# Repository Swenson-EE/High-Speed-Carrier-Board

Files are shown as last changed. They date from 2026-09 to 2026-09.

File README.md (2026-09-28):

# LattePanda-Mu High-Speed Carrier Board

A custom carrier board designed for the **LattePanda Mu** compute module, with a focus on high-speed digital design, signal integrity, power distribution, and practical PCB design.

This project was developed to apply high-speed PCB design concepts to a real embedded computing platform. The design process incorporated concepts studied through online courses, technical forums, datasheets, and reference designs.

> **Project Status:** Fabrication
> **PCB Design Tool:** KiCad
> **Primary Focus:** High-speed digital design, power distribution, signal integrity, and embedded hardware

---

## Overview

The goal of this project is to design a custom carrier board around the LattePanda Mu rather than relying on an off-the-shelf carrier board to explore high-speed digital design concepts.

The carrier board is intended to provide practical interfaces for development and experimentation while giving me experience designing a PCB containing multiple high-speed interfaces.

### Design Goals

- Develop a custom carrier board for the LattePanda Mu
- Apply high-speed PCB layout techniques
- Develop controlled-impedance routing practices
- Maintain appropriate differential-pair geometry
- Minimize high-speed signal discontinuities
- Develop a robust power distribution network
- Practice schematic-to-PCB design workflows
- Use datasheets and reference documentation to make design decisions
- Validate the design using available electrical and PCB design tools
- Produce a board suitable for fabrication and bring-up

---

## Hardware

### Compute Module

**LattePanda Mu**

The LattePanda Mu provides the primary compute platform for the carrier board.

The carrier board interfaces with the module through its high-density connectors and routes the available interfaces to the desired peripherals and connectors.

---

## PCB Designs

<table style="background: white;">
  <tr>
    <td align="center"><b>Top Silk Screen</b><br></td>
  </tr>
  <tr>
    <td align="center"><b>Front Cu (L1)</b><br></td>
  </tr>
  <tr>
    <td align="center"><b>GND (L2)</b><br></td>
  </tr>
  <tr>
    <td align="center"><b>PWR (L3)</b><br></td>
  </tr>
  <tr>
    <td align="center"><b>Bottom Cu (L4)</b><br></td>
  </tr>
</table>

## Interfaces

The carrier board is designed around several interfaces provided by the LattePanda Mu.

| Interface | Purpose | Design Considerations |
| --- | --- | --- |
| USB | Peripheral connectivity | High-speed differential routing |
| HDMI / Display | Display output | Differential high-speed routing |
| Ethernet | Network connectivity | Differential pairs and magnetics |
| PCIe | Expansion | Controlled impedance / differential routing |
| M.2 | Expansion/storage | High-speed differential routing |
| GPIO | General-purpose I/O | Digital signal integrity |
| Power | Module and peripheral power | Power integrity / decoupling |

---

# High-Speed PCB Design

A major purpose of this project is to practice PCB design techniques applicable to high-speed digital hardware.

Rather than treating PCB traces simply as electrical connections, the design considers them as transmission lines at sufficiently high signal frequencies.

Areas being considered include:

### Controlled Impedance

High-speed interfaces are routed using appropriate controlled-impedance structures based on the PCB stackup and manufacturer's capabilities.

Examples include:

- Differential impedance
- Single-ended impedance
- Trace width
- Trace spacing
- Reference planes
- Dielectric thickness
- Copper thickness

The final trace geometries are based on the selected PCB stackup rather than relying solely on generic routing rules.

### Differential Pairs

High-speed differential interfaces are routed as matched differential pairs where required.

Design considerations include:

- Differential impedance
- Pair spacing
- Intra-pair length matching
- Continuous reference planes
- Avoiding unnecessary vias
- Minimizing discontinuities
- Maintaining consistent routing geometry

### Return Paths

High-speed signal routing considers the return current path rather than treating the signal trace independently.

Particular attention is given to:

- Continuous reference planes
- Plane transitions
- Ground vias
- Layer transitions
- Signal crossings
- Connector transitions

### Via Design

Vias can introduce discontinuities into high-speed signals.

Where applicable, the design considers:

- Via stubs
- Via placement
- Differential via geometry
- Ground-via placement
- Layer transitions
- Back-drilling requirements

---

# Power Distribution

The carrier board includes power regulation and distribution for the compute module and attached peripherals.

Power design considerations include:

- Input power requirements
- Voltage regulation
- Current requirements
- Decoupling
- Ground-plane design

Decoupling capacitors are placed with consideration for the physical connection between the capacitor, power pin, and return path rather than simply placing them near the associated component.

---

# PCB Stackup

The PCB stackup is an important part of the high-speed design.

The stackup is selected based on the requirements of the interfaces being routed and the capabilities of the intended PCB manufacturer.

Example stackup:

| Layer | Function |
| ----- | --- |
| L1 | Signal |
| L2 | Ground |
| L3 | Power |
| L4 | Signal |

The stackup is used to determine the appropriate controlled-impedance trace geometries.

---

# Research & Learning

This project is also a practical study of high-speed PCB design.

The design process has been informed by:

- LattePanda Mu documentation
- Component datasheets
- Manufacturer application notes
- PCB fabrication guidelines
- High-speed PCB design coursework
- Engineering forums
- Technical discussions
- Reference designs
- Signal-integrity design practices

The purpose of using these resources is to understand **why** particular PCB design decisions are made rather than simply reproducing an existing board.

Where external designs or reference material influence the project, the relevant source will be documented in the project documentation.

---

# Verification

Before fabrication, the design will be reviewed using:

- Electrical rule checking
- PCB design rule checking
- Connectivity verification
- Differential-pair constraints
- Length matching constraints
- Controlled-impedance calculations
- Power-tree review
- Datasheet requirement verification
- Manufacturer design-rule review

Where practical, calculations and design assumptions will be documented in the `/docs` directory.

---

# Disclaimer

This is an independent educational hardware project.

The project is intended to demonstrate my understanding and application of PCB design principles. It is not an official LattePanda design.

The design should be independently reviewed and validated before being used in a production or safety-critical application.

---

# References

- LattePanda Mu documentation
- LattePanda Mu hardware/reference documentation
- Relevant component datasheets
- PCB manufacturer fabrication specifications
- High-speed PCB design course material
- Relevant application notes and technical references

---

## Author

**Tyler Swenson**

This project was created as a hands-on embedded hardware and high-speed PCB design project, with an emphasis on understanding the engineering decisions behind the design rather than simply producing a functioning PCB.

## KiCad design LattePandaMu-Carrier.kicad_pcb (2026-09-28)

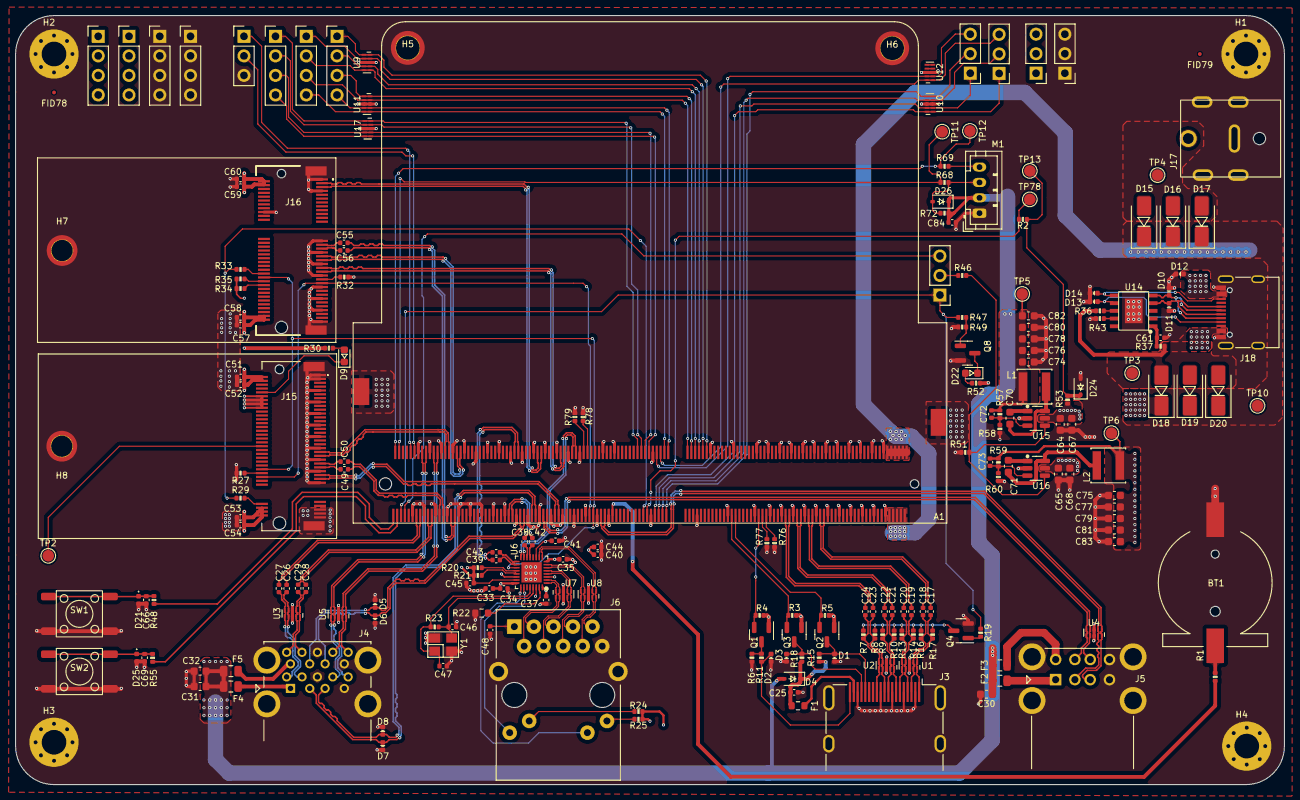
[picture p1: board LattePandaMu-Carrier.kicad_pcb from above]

Board: 4 copper layers, 165.0 x 100.0 mm, 218 parts (0 on the bottom side), 174 nets.

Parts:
A1: LattePanda_Mu; LattePanda_Module_H8.0mm_Horizontal
BT1: Battery_Cell; Battery_Holder_CR1220_S8411-45R
C17, C18, C19, C20, C21, C22, C23, C24, C25, C26, C27, C28, C29, C33, C34, C35, C37, C38, C39, C40, C41, C42, C43, C45, C48, C52, C54, C58, C60, C84: 100nF/50V; C_0402_1005Metric
C30, C31, C32, C64, C65, C67, C68, C74, C75, C76, C77, C80, C81, C82, C83: 22uF/10V; C_0603_1608Metric
C44: 10uF/50V; C_0402_1005Metric
C46, C47, C72, C73: 12pF/50V; C_0402_1005Metric
C49, C50, C55, C56: 220nF/50V; C_0402_1005Metric
C51, C53, C57, C59: 10uF/10V; C_0402_1005Metric
C61, C66, C69: 1uF/16V; C_0402_1005Metric
C70, C71, C78, C79: 100nF/50V; C_0603_1608Metric
D1, D2, D3, D5, D6, D7, D8: ESD5V0B03; D_0402_1005Metric
D4, D26: 1N5819WS; D_SOD-323
D9: LED_G; LED_0603_1608Metric
D10, D11, D21, D25: ESD9B5.0ST5G; D_0402_1005Metric
D12, D13, D14: D_Zener; D_0402_1005Metric
D15, D16, D17, D18, D19, D20: D_Schottky; D_SMA
D22: LED; LED_0603_1608Metric
D24: 3V3 Izt=5mA; D_SOD-323
F1: 6V/50mA; R_0603_1608Metric
F2, F3, F4, F5: 6V/1A; Fuse_0805_2012Metric
FID78, FID79: Fiducial; Fiducial_0.5mm_Mask1mm
H1, H2, H3, H4: MountingHole_Pad; MountingHole_3.2mm_M3_Pad_Via
H5, H6: MountingHole_Pad; MountingHole_3mm_M2_Pad_TopOnly
H7, H8: MountingHole_M2.0; MountingHole_2.7mm_M2_Pad_TopOnly
J1, J8, J10, J11, J14: Conn_01x03_Pin; PinHeader_1x03_P2.54mm_Vertical
J3: HDMI_A; HDMI_A_Molex_208658-1001_Horizontal
J4: USB3_A_Stacked; USB3_A_Molex_48406-0001_Horizontal_Stacked
J5: USB_A_Stacked; USB_A_CUI_UJ2-ADH-TH_Horizontal_Stacked
J6: RJ45_RB1-125B8G1A; RJ45_UDE_RB1-125B8G1A
J7, J9, J12, J13, J19, J20, J21: Conn_01x04_Pin; PinHeader_1x04_P2.54mm_Vertical
J15: Bus_M.2_Socket_M; PCIe_M.2_Connectors_P=0.5mm_H=4.2mm_KeyM
J16: Bus_M.2_Socket_E; PCIe_M.2_Connectors_P=0.5mm_H=4.2mm_KeyE
J17: Barrel_Jack_Switch; DC_Jack_DC007B_30V_10A
J18: USB_C_Receptacle_USB2.0_16P; USB_C_Receptacle_G-Switch_GT-USB-7010ASV
JP1: Jumper_3_Bridged12; PinHeader_1x03_P2.54mm_Vertical
L1, L2: 2.2uH/4.3A; L_Sunlord_SWPA4020S
M1: Fan_4pin; JST_PH_B4B-PH-K_1x04_P2.00mm_Vertical
Q1, Q2, Q3, Q4: 2SK3018; SOT-23
Q8: 2N7002; SOT-23
R1, R11, R37, R47: 1k/1%; R_0402_1005Metric
R2, R20, R21, R34, R35, R36, R49, R58, R78, R79: 10k/1%; R_0402_1005Metric
R3, R5, R15, R18, R19, R52, R53: 2.2k/1%; R_0402_1005Metric
R4, R23: 1M/1%; R_0402_1005Metric
R6, R59, R68: 21.5k/1%; R_0402_1005Metric
R7, R8, R9, R10, R13, R14, R16, R17, R24, R25: 470R/1%; R_0402_1005Metric
R22: 2.49k/1%; R_0603_1608Metric
R27, R29, R32, R33: 0R/1%; R_0402_1005Metric
R30: 2.2K/1%; R_0402_1005Metric
R43: 56k/1%; R_0402_1005Metric
R46, R51, R76, R77: 100k/1%; R_0402_1005Metric
R48, R55, R69: 100R/1%; R_0402_1005Metric
R57: 75k/1%; R_0402_1005Metric
R60, R72: 4.7k/1%; R_0402_1005Metric
SW1, SW2: SW_Push; SW_Push_6x6x6
TP2, TP3, TP4, TP5, TP6, TP10, TP11, TP12, TP13, TP78: TestPoint; TestPoint_Pad_D1.5mm
U1, U2, U3, U4, U5: D3V3XA4B10LP; Diodes_UDFN-10_1.0x2.5mm_P0.5mm
U6: RTL8111H-CG-RH; QFN-32-1EP_4x4mm_P0.4mm_EP2.65x2.65mm
U7, U8, U9, U10, U11, U12, U17: ULC0524P; Diodes_UDFN-10_1.0x2.5mm_P0.5mm
U14: USB PD等快充协议受电芯片-CH224K-ESSOP10; ESSOP-10-1EP_3.9x5mm_P1.0mm_EP3.2x2.3
U15, U16: LM2734X; TSOT-23-6
Y1: 25MHz; Crystal_SMD_3225-4Pin_3.2x2.5mm

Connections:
5V_HDMI_VCC: C25.1, D4.1 (K), F1.1, R15.2, R18.2
+1V0: C33.2, C34.2, C35.2, C40.2, C44.2, U6.3 (AVDD10), U6.8 (AVDD10), U6.22 (DVDD10), U6.24 (REGOUT), U6.30 (AVDD10)
+3.3V: C37.2, C41.2, C45.2, C51.1, C52.1, C53.1, C54.1, C57.1, C58.1, C59.1, C60.1, C73.1, C75.1, C77.1, C79.1, C81.1, C83.1, J13.1, J13.2, J13.3, J13.4, J14.1, J14.2, J14.3, J15.2 (3.3V), J15.4 (3.3V), J15.12 (3.3V), J15.14 (3.3V), J15.16 (3.3V), J15.18 (3.3V), J15.70 (3.3V), J15.72 (3.3V), J15.74 (3.3V), J16.2 (3.3V), J16.4 (3.3V), J16.72 (3.3V), J16.74 (3.3V), J21.1, J21.2, J21.3, J21.4, L2.2, Q1.1 (G), Q2.1 (G), Q3.1 (G), R3.2, R4.2, R5.2, R20.2, R21.2, R24.2, R25.2, R30.2, R34.2, R35.2, R52.2, R59.2, TP6.1 (1_1), U6.11 (AVDD33), U6.23 (VDDREG), U6.32 (AVDD33)
+5V: C30.2, C31.2, C32.2, C72.1, C74.1, C76.1, C78.1, C80.1, C82.1, C84.1, D4.2 (A), D26.1 (K), F2.1, F3.1, F4.1, F5.1, L1.2, M1.2 (+), R57.2, R72.1, TP5.1 (1_1)
+12V: D15.2 (A), D16.2 (A), D17.2 (A), J17.1, TP4.1 (1_1)
+15V: D12.1 (K), D18.2 (A), D19.2 (A), D20.2 (A), J18.A4 (VBUS), J18.A9 (VBUS), J18.B4 (VBUS), J18.B9 (VBUS), R36.1, R37.1, TP3.1 (1_1)
+BATT: A1.115 (VBAT), R1.2
/Fan/FAN_1_PWM: A1.2 (FAN1_PWM), R69.1, TP12.1 (1_1)
/Fan/FAN_1_TAC: A1.4 (FAN1_TAC), R68.1, TP11.1 (1_1)
/GPIO/GPP_D0: A1.128 (GPP_D0), J19.1, U17.1, U17.10 (NC)
/GPIO/GPP_D1: A1.130 (GPP_D1), J19.2, U17.2, U17.9 (NC)
/GPIO/GPP_D2: A1.132 (GPP_D2), J19.3, U17.4, U17.7 (NC)
/GPIO/GPP_D3: A1.134 (GPP_D3), J19.4, U17.5, U17.6 (NC)
/GPIO/I2C2_SCL: A1.154 (I2C2_SCL), J9.1, U9.2, U9.9 (NC)
/GPIO/I2C2_SDA: A1.156 (I2C2_SDA), J7.1, U9.1, U9.10 (NC)
/GPIO/I2C3_SCL: A1.150 (I2C3_SCL), J9.2, U9.5, U9.6 (NC)
/GPIO/I2C3_SDA: A1.152 (I2C3_SDA), J7.2, U9.4, U9.7 (NC)
/GPIO/I2C4_SCL: A1.146 (I2C4_SCL), J9.3, U11.2, U11.9 (NC)
/GPIO/I2C4_SDA: A1.148 (I2C4_SDA), J7.3, U11.1, U11.10 (NC)
/GPIO/I2C5_SCL: A1.142 (I2C5_SCL), J9.4, U11.5, U11.6 (NC)
/GPIO/I2C5_SDA: A1.144 (I2C5_SDA), J7.4, U11.4, U11.7 (NC)
/GPIO/SOC_UART0_RX: A1.137 (UART0_RXD), J8.1, U10.1, U10.10 (NC)
/GPIO/SOC_UART0_TX: A1.139 (UART0_TXD), J10.1, U10.2, U10.9 (NC)
/GPIO/SOC_UART1_RX: A1.141 (UART1_RXD), J8.2, U10.4, U10.7 (NC)
/GPIO/SOC_UART1_TX: A1.143 (UART1_TXD), J10.2, U10.5, U10.6 (NC)
/GPIO/SOC_UART2_RX: A1.140 (UART2_RXD), J8.3, U12.1, U12.10 (NC)
/GPIO/SOC_UART2_TX: A1.138 (UART2_TXD), J10.3, U12.2, U12.9 (NC)
/Gigabit Ethernet/GbE_PCIe_CLK+: A1.94 (REFCLK4+), U6.15 (REFCLK_P)
/Gigabit Ethernet/GbE_PCIe_CLK-: A1.96 (REFCLK4-), U6.16 (REFCLK_N)
/Gigabit Ethernet/GbE_PCIe_RX+: A1.64 (HSIO6_RX+), C43.1
/Gigabit Ethernet/GbE_PCIe_RX-: A1.66 (HSIO6_RX-), C39.1
/Gigabit Ethernet/GbE_PCIe_TX+: A1.61 (HSIO6_TX+), C42.1
/Gigabit Ethernet/GbE_PCIe_TX-: A1.63 (HSIO6_TX-), C38.1
/Gigabit Ethernet/HSI+: C42.2, U6.13 (HSIP)
/Gigabit Ethernet/HSI-: C38.2, U6.14 (HSIN)
/Gigabit Ethernet/HSO+: C43.2, U6.17 (HSOP)
/Gigabit Ethernet/HSO-: C39.2, U6.18 (HSON)
/Gigabit Ethernet/LED1_1000: J6.L4, U6.26 (LED1)
/Gigabit Ethernet/LED2_ACT: J6.L2, U6.25 (LED2)
/Gigabit Ethernet/MDI0+: J6.R2 (TD1+), U6.1 (MDIP0), U7.1, U7.10 (NC)
/Gigabit Ethernet/MDI0-: J6.R3 (TD1-), U6.2 (MDIN0), U7.2, U7.9 (NC)
/Gigabit Ethernet/MDI1+: J6.R4 (TD2+), U6.4 (MDIP1), U7.4, U7.7 (NC)
/Gigabit Ethernet/MDI1-: J6.R5 (TD2-), U6.5 (MDIN1), U7.5, U7.6 (NC)
/Gigabit Ethernet/MDI2+: J6.R6 (TD3+), U6.6 (MDIP2), U8.5, U8.6 (NC)
/Gigabit Ethernet/MDI2-: J6.R7 (TD3-), U6.7 (MDIN2), U8.4, U8.7 (NC)
/Gigabit Ethernet/MDI3+: J6.R8 (TD4+), U6.9 (MDIP3), U8.2, U8.9 (NC)
/Gigabit Ethernet/MDI3-: J6.R9 (TD4-), U6.10 (MDIN3), U8.1, U8.10 (NC)
/HDMI/DDC_SCL: D1.2 (A2), J3.15 (SCL), Q2.3 (D), R15.1
/HDMI/DDC_SDA: D3.2 (A2), J3.16 (SDA), Q3.3 (D), R18.1
/HDMI/DDI_B_DDC_SCL: A1.171 (DDIB_DDC_SCL), Q2.2 (S), R5.1
/HDMI/DDI_B_DDC_SDA: A1.169 (DDIB_DDC_SDA), Q3.2 (S), R3.1
/HDMI/DDI_B_HPD: A1.183 (DDIB_HPD), Q1.2 (S), R4.1
/HDMI/DDI_B_TX0+: A1.217 (DDIB_TX0+), C17.1
/HDMI/DDI_B_TX0-: A1.215 (DDIB_TX0-), C18.1
/HDMI/DDI_B_TX1+: A1.211 (DDIB_TX1+), C19.1
/HDMI/DDI_B_TX1-: A1.209 (DDIB_TX1-), C20.1
/HDMI/DDI_B_TX2+: A1.205 (DDIB_TX2+), C21.1
/HDMI/DDI_B_TX2-: A1.203 (DDIB_TX2-), C22.1
/HDMI/DDI_B_TX3+: A1.199 (DDIB_TX3+), C23.1
/HDMI/DDI_B_TX3-: A1.197 (DDIB_TX3-), C24.1
/HDMI/HPD: D2.2 (A2), J3.19 (HPD), R11.1
/HDMI/TMDS_CK+: C23.2, J3.10 (CK+), R8.2, U2.4, U2.7 (NC)
/HDMI/TMDS_CK-: C24.2, J3.12 (CK-), R7.2, U2.5, U2.6 (NC)
/HDMI/TMDS_D0+: C21.2, J3.7 (D0+), R10.2, U2.1, U2.10 (NC)
/HDMI/TMDS_D0-: C22.2, J3.9 (D0-), R9.2, U2.2, U2.9 (NC)
/HDMI/TMDS_D1+: C19.2, J3.4 (D1+), R14.2, U1.4, U1.7 (NC)
/HDMI/TMDS_D1-: C20.2, J3.6 (D1-), R13.2, U1.5, U1.6 (NC)
/HDMI/TMDS_D2+: C17.2, J3.1 (D2+), R17.2, U1.1, U1.10 (NC)
/HDMI/TMDS_D2-: C18.2, J3.3 (D2-), R16.2, U1.2, U1.9 (NC)
/LattePanda Module/HSIO_0_TX+: A1.13 (HSIO0_TX+), C27.1
/LattePanda Module/HSIO_0_TX-: A1.15 (HSIO0_TX-), C26.1
/LattePanda Module/HSIO_1_TX+: A1.19 (HSIO1_TX+), C29.1
/LattePanda Module/HSIO_1_TX-: A1.21 (HSIO1_TX-), C28.1
/LattePanda Module/HSIO_2_RX+: A1.28 (HSIO2_RX+), J15.43 (PERp0/SATA-B-)
/LattePanda Module/HSIO_2_RX-: A1.30 (HSIO2_RX-), J15.41 (PERn0/SATA-B+)
/LattePanda Module/HSIO_2_TX+: A1.25 (HSIO2_TX+), C49.1
/LattePanda Module/HSIO_2_TX-: A1.27 (HSIO2_TX-), C50.1
/LattePanda Module/HSIO_3_RX+: A1.34 (HSIO3_RX+), J16.41 (PERp0)
/LattePanda Module/HSIO_3_RX-: A1.36 (HSIO3_RX-), J16.43 (PERn0)
/LattePanda Module/HSIO_3_TX+: A1.31 (HSIO3_TX+), C55.1
/LattePanda Module/HSIO_3_TX-: A1.33 (HSIO3_TX-), C56.1
/LattePanda Module/REFCLK_0+: A1.85 (REFCLK0+), J15.55 (REFCLKp)
/LattePanda Module/REFCLK_0-: A1.87 (REFCLK0-), J15.53 (REFCLKn)
/LattePanda Module/REFCLK_3+: A1.88 (REFCLK3+), J16.47 (REFCLKp0)
/LattePanda Module/REFCLK_3-: A1.90 (REFCLK3-), J16.49 (REFCLKn0)
/LattePanda Module/SLS_S3: A1.7 (SLS_S3), JP1.3 (B)
/LattePanda Module/SUSCLK_WIFI: A1.131 (SUSCLK), R29.2, R33.2
/LattePanda Module/USB_2_P7+: A1.76 (USB2_P7+), J16.3 (USB_D+)
/LattePanda Module/USB_2_P7-: A1.78 (USB2_P7-), J16.5 (USB_D-)
/LattePanda Module/~PWR_SW: A1.1 (~PWRBTN), R48.1
/LattePanda Module/~RST_SW: A1.3 (~RSTBTN), R55.1
/M.2 M Key/CON_PCIE_TX1+: C49.2, J15.49 (PETp0/SATA-A+)
/M.2 M Key/CON_PCIE_TX1-: C50.2, J15.47 (PETn0/SATA-A-)
/M.2 M Key/CON_PCIE_TX_0+: C55.2, J16.35 (PETp0)
/M.2 M Key/CON_PCIE_TX_0-: C56.2, J16.37 (PETn0)
/M.2 M Key/~CLKREQE: J16.53 (~CLKREQ0), R32.1
/M.2 M Key/~CLKREQM: J15.52 (~CLKREQ), R27.1
/Power Supply/CC1: D13.1 (K), J18.A5 (CC1), U14.7 (CC1)
/Power Supply/CC2: D14.1 (K), J18.B5 (CC2), U14.6 (CC2)
/Power Supply/PWR_C_D+: D11.2 (A2), J18.A6 (D+), J18.B6 (D+), U14.4 (DP)
/Power Supply/PWR_C_D-: D10.2 (A2), J18.A7 (D-), J18.B7 (D-), U14.5 (DM)
/Power Supply/PWR_EN: R46.2, R51.2, U15.4 (EN), U16.4 (EN)
/USB 2.0 & 3.0/CON_USB1_D_N: A1.109 (USB2_P5-), J5.2 (D1-), U4.2, U4.9 (NC)
/USB 2.0 & 3.0/CON_USB1_D_P: A1.111 (USB2_P5+), J5.3 (D1+), U4.1, U4.10 (NC)
/USB 2.0 & 3.0/CON_USB2_D_N: A1.79 (USB2_P3-), J5.6 (D2-), U4.5, U4.6 (NC)
/USB 2.0 & 3.0/CON_USB2_D_P: A1.81 (USB2_P3+), J5.7 (D2+), U4.4, U4.7 (NC)
/USB 2.0 & 3.0/CON_USB3_D_N: A1.73 (USB2_P2-), D8.1 (A1), J4.2 (D1-)
/USB 2.0 & 3.0/CON_USB3_D_P: A1.75 (USB2_P2+), D7.1 (A1), J4.3 (D1+)
/USB 2.0 & 3.0/CON_USB3_SSRX_N: A1.18 (HSIO0_RX-), J4.5 (SSRX1-), U5.4, U5.7 (NC)
/USB 2.0 & 3.0/CON_USB3_SSRX_P: A1.16 (HSIO0_RX+), J4.6 (SSRX1+), U5.5, U5.6 (NC)
/USB 2.0 & 3.0/CON_USB3_SSTX_N: C26.2, J4.8 (SSTX1-), U3.4, U3.7 (NC)
/USB 2.0 & 3.0/CON_USB3_SSTX_P: C27.2, J4.9 (SSTX1+), U3.5, U3.6 (NC)
/USB 2.0 & 3.0/CON_USB4_D_N: A1.67 (USB2_P1-), D6.1 (A1), J4.11 (D2-)
/USB 2.0 & 3.0/CON_USB4_D_P: A1.69 (USB2_P1+), D5.1 (A1), J4.12 (D2+)
/USB 2.0 & 3.0/CON_USB4_SSRX_N: A1.24 (HSIO1_RX-), J4.14 (SSRX2-), U5.1, U5.10 (NC)
/USB 2.0 & 3.0/CON_USB4_SSRX_P: A1.22 (HSIO1_RX+), J4.15 (SSRX2+), U5.2, U5.9 (NC)
/USB 2.0 & 3.0/CON_USB4_SSTX_N: C28.2, J4.17 (SSTX2-), U3.1, U3.10 (NC)
/USB 2.0 & 3.0/CON_USB4_SSTX_P: C29.2, J4.18 (SSTX2+), U3.2, U3.9 (NC)
/~PEWAKE: A1.103 (~WAKE), J15.54 (~PEWAKE), J16.55 (~PEWAKE0)
/~PLT_RST: A1.105 (~PLTRST), J15.50 (~PERST), J16.52 (~PERST0), U6.19 (PERSTB)
/~PWR_LED/~PSON: A1.5 (SLS_S0), JP1.1 (A), R19.1, R47.1
GND: A1.11 (GND), A1.14 (GND), A1.17 (GND), A1.20 (GND), A1.23 (GND), A1.26 (GND), A1.29 (GND), A1.32 (GND), A1.35 (GND), A1.38 (GND), A1.41 (GND), A1.44 (GND), A1.47 (GND), A1.50 (GND), A1.53 (GND), A1.56 (GND), A1.59 (GND), A1.62 (GND), A1.65 (GND), A1.68 (GND), A1.71 (GND), A1.74 (GND), A1.77 (GND), A1.80 (GND), A1.83 (GND), A1.86 (GND), A1.89 (GND), A1.92 (GND), A1.95 (GND), A1.98 (GND), A1.101 (GND), A1.107 (GND), A1.110 (GND), A1.113 (GND), A1.116 (GND), A1.135 (GND), A1.136 (GND), A1.151 (GND), A1.158 (GND), A1.167 (GND), A1.170 (GND), A1.181 (GND), A1.182 (GND), A1.188 (GND), A1.189 (GND), A1.194 (GND), A1.195 (GND), A1.200 (GND), A1.201 (GND), A1.206 (GND), A1.207 (GND), A1.212 (GND), A1.213 (GND), A1.218 (GND), A1.219 (GND), A1.224 (GND), A1.225 (GND), A1.230 (GND), A1.231 (GND), A1.236 (GND), A1.237 (GND), A1.242 (GND), A1.243 (GND), A1.248 (GND), A1.249 (GND), A1.MP (Mountinge_Pads), BT1.2 (-), C25.2, C30.1, C31.1, C32.1, C33.1, C34.1, C35.1, C37.1, C40.1, C41.1, C44.1, C45.1, C46.2, C47.2, C48.1, C51.2, C52.2, C53.2, C54.2, C57.2, C58.2, C59.2, C60.2, C61.2, C64.2, C65.1, C66.2, C67.2, C68.1, C69.2, C74.2, C75.2, C76.2, C77.2, C78.2, C79.2, C80.2, C81.2, C82.2, C83.2, C84.2, D1.1 (A1), D2.1 (A1), D3.1 (A1), D5.2 (A2), D6.2 (A2), D7.2 (A2), D8.2 (A2), D10.1 (A1), D11.1 (A1), D12.2 (A), D13.2 (A), D14.2 (A), D21.2 (A2), D24.2 (A), D25.2 (A2), H1.1 (1_1), H2.1 (1_1), H3.1 (1_1), H4.1 (1_1), H5.1 (1_1), H6.1 (1_1), H7.1 (1_1), H8.1 (1_1), J1.3, J3.2 (D2S), J3.5 (D1S), J3.8 (D0S), J3.11 (CKS), J3.17 (GND), J3.SH, J4.4 (GND1), J4.7 (DRAIN1), J4.13 (GND2), J4.16 (DRAIN2), J4.19 (SHIELD), J5.4 (GND1), J5.8 (GND2), J5.9 (Shield), J6.R10 (GND), J6.SH, J11.1, J11.2, J11.3, J12.1, J12.2, J12.3, J12.4, J15.1 (GND), J15.3 (GND), J15.9 (GND), J15.15 (GND), J15.21 (GND), J15.27 (GND), J15.33 (GND), J15.39 (GND), J15.45 (GND), J15.51 (GND), J15.57 (GND), J15.71 (GND), J15.73 (GND), J15.75 (GND), J15.MP1, J15.MP2, J16.1 (GND), J16.7 (GND), J16.18 (GND), J16.33 (GND), J16.39 (GND), J16.45 (GND), J16.51 (GND), J16.57 (GND), J16.63 (GND), J16.69 (GND), J16.75 (GND), J16.MP1, J16.MP2, J17.2, J17.3, J18.A1 (GND), J18.A12 (GND), J18.B1 (GND), J18.B12 (GND), J18.S1 (SHIELD), J20.1, J20.2, J20.3, J20.4, M1.1 (-), Q4.2 (S), Q8.2 (S), R6.1, R22.1, R27.2, R32.2, R43.2, R49.1, R51.1, R58.1, R60.1, R76.2, R77.2, R78.1, R79.1, SW1.2, SW2.2, U1.3 (VSS), U1.8 (VSS), U2.3 (VSS), U2.8 (VSS), U3.3 (VSS), U3.8 (VSS), U4.3 (VSS), U4.8 (VSS), U5.3 (VSS), U5.8 (VSS), U6.33 (GND), U7.3 (VSS), U7.8 (VSS), U8.3 (VSS), U8.8 (VSS), U9.3 (VSS), U9.8 (VSS), U10.3 (VSS), U10.8 (VSS), U11.3 (VSS), U11.8 (VSS), U12.3 (VSS), U12.8 (VSS), U14.0 (GND), U15.2 (GND), U16.2 (GND), U17.3 (VSS), U17.8 (VSS), Y1.2 (G), Y1.4 (G)
unnamed: A1.12 (SIO_UART_RX), J1.2
unnamed: A1.10 (SIO_UART_TX), J1.1
unnamed: A1.187 (TCP0_HPD), R76.1
unnamed: A1.185 (TCP1_HPD), R77.1
unnamed: A1.133 (~BIOS_SEL), R2.1, TP78.1 (1_1)
unnamed: A1.100 (~CLKREQ3), R79.2
unnamed: A1.102 (~CLKREQ4), R78.2
unnamed: BT1.1 (+), R1.1
unnamed: D9.2 (A), R30.1
unnamed: D9.1 (K), J15.10 (DAS/~DSS/~LED1)
unnamed: C66.1, D21.1 (A1), R48.2, SW1.1
unnamed: D22.2 (A), R52.1
unnamed: D22.1 (K), Q8.3 (D)
unnamed: C69.1, D25.1 (A1), R55.2, SW2.1
unnamed: D26.2 (A), M1.3 (Tacho), R68.2, R72.2
unnamed: F1.2, J3.18 (+5V)
unnamed: F4.2, J4.1 (VBUS1)
unnamed: F5.2, J4.10 (VBUS2)
unnamed: F2.2, J5.1 (VBUS1)
unnamed: F3.2, J5.5 (VBUS2)
unnamed: C48.2, J6.R1 (CT)
unnamed: J6.L1, R25.1
unnamed: J6.L3, R24.1
unnamed: J15.38 (DEVSLP), TP2.1 (1_1)
unnamed: J15.68 (SUSCLK), R29.1
unnamed: J16.50 (SUSCLK), R33.1
unnamed: J16.56 (~W_DISABLE1), R34.1
unnamed: J16.54 (~W_DISABLE2), R35.1
unnamed: JP1.2 (C), R46.1
unnamed: M1.4 (PWM), R69.2
unnamed: Q1.3 (D), R6.2, R11.2
unnamed: Q4.3 (D), R7.1, R8.1, R9.1, R10.1, R13.1, R14.1, R16.1, R17.1
unnamed: Q4.1 (G), R19.2
unnamed: Q8.1 (G), R47.2, R49.2
unnamed: C47.1, R23.1, U6.28 (CKXTAL1), Y1.1
unnamed: C46.1, R23.2, U6.29 (CKXTAL2), Y1.3
unnamed: R20.1, U6.20 (ISOLATEB)
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

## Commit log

2026-07-23 Project setup with LattePande-Mu symbol and footprints
    [LattePandaMu-Carrier.kicad_pcb, LattePandaMu-Carrier.kicad_sch]
2026-07-23 feat: Imported LattePanda-Mu settings
    [LattePandaMu-Carrier.kicad_sch]
2026-07-23 feat: Added hierarchical sheets
    [LattePandaMu-Carrier.kicad_sch, LattePanda_Module.kicad_sch, ethernet.kicad_sch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]
2026-07-28 feat: Added hierarchical sheets and pins
    [LattePandaMu-Carrier.kicad_sch, LattePanda_Module.kicad_sch, ethernet.kicad_sch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]
2026-07-28 feat(psu): Added USB-C power circuit
    [psu.kicad_sch]
2026-07-28 feat(psu): Added barrel jack connector circuit
    [psu.kicad_sch]
2026-07-28 fix(psu): Fixed wiring error in usb-c circuit
    [psu.kicad_sch]
2026-07-28 feat(psu): Added PCIe power
    - Do not populate, but there for future possible use.
    [psu.kicad_sch]
2026-07-28 feat(psu): Added 5V and 3.3V outputs
    [psu.kicad_sch]
2026-07-28 feat(psu): Added power and reset buttons
    - Also added extra labels and documentation.
    [psu.kicad_sch]
2026-07-29 feat: Ran ERC and fixed missing annotations and wiring errors
    [psu.kicad_sch]
2026-07-29 feat(psu): Connected psu hierarchical pins to LattePanda sheet
    [LattePandaMu-Carrier.kicad_sch]
2026-07-29 feat(fan): Added fan circuit and connected sheet pins
    [LattePandaMu-Carrier.kicad_sch, fan.kicad_sch]
2026-07-29 feat(gpio): Added gpio circuit and connections
    [LattePandaMu-Carrier.kicad_sch, gpio.kicad_sch]
2026-07-29 feat(pcie): Added PCIe x4 implementation and connections.
    [LattePandaMu-Carrier.kicad_sch, picex4.kicad_sch]
2026-07-29 feat(ethernet): Added Gigabit Ethernet implementation and connections.
    [LattePandaMu-Carrier.kicad_sch, ethernet.kicad_sch]
2026-07-29 feat(usb): Added usb 2.0 & usb 3.0 implementation and connections.
    [LattePandaMu-Carrier.kicad_sch, usb_2_3.kicad_sch]
2026-07-29 feat(hdmi): Added HDMI implementation and connections.
    [LattePandaMu-Carrier.kicad_sch, hdmi.kicad_sch, usb_2_3.kicad_sch]
2026-07-29 feat(m.2): Added m.2 E and M keys
    [LattePandaMu-Carrier.kicad_sch, m2_em_key.kicad_sch]
2026-09-09 feat(pcb): Layout editor setup and basic configuration.
    [LattePandaMu-Carrier.kicad_pcb]
2026-09-09 feat(pcb): Board outline and import
    [LattePandaMu-Carrier.kicad_pcb]
2026-09-09 fix: Set missing footprints and fixed missing pin-pad connections.
    - J15, J16 missing MP1 and MP2 pins. Fixed in pin table within the symbol editor for each symbol.
    - A ll USB receptacles J4, J5, J18 had mismatched pin numbers for the pcb symbol footprint. Renamed to match.
    - Fixed various DNP components that were not excluded from the board.
    - Fixed remaining missing footprints.
    [LattePandaMu-Carrier.kicad_pcb, LattePandaMu-Carrier.kicad_sch, LattePanda_Module.kicad_sch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]
2026-09-09 feat: Impedance and stackup calculations.
    Performed impedance calculations for 90 and 100 ohm impedences via NextPCB.
    https://www.nextpcb.com/pcb-quote
    https://www.nextpcb.com/pcb-impedance-calculator
2026-09-10 fix: Fixed DNP parts populating on the board.
    [LattePandaMu-Carrier.kicad_pcb, ethernet.kicad_sch, fan.kicad_sch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]
2026-09-10 feat(layout): Main component placement.
    [LattePandaMu-Carrier.kicad_pcb]
2026-09-10 feat(layout): Respositioned M.2 keys for better routing.
    - Repositioned other components that interfered.
    [LattePandaMu-Carrier.kicad_pcb]
2026-09-19 feat(routing): Routed M.2 differential pairs and tuned skew for differential pairs.
    [LattePandaMu-Carrier.kicad_pcb]
2026-09-19 feat(routing): Routed low-speed M.2 signals to related resistors and components.
    - Did not route signals directly to LattePandaMu, waiting until all differential pairs are routed.
    - Did not route power.
    [LattePandaMu-Carrier.kicad_pcb]
2026-09-19 feat(routing): Routed hdmi differential pairs.
    - TMDS_D1+/- shows + and - equal skew on both sides, so tuning was ignored for this pair.
    [LattePandaMu-Carrier.kicad_pcb]
2026-09-19 feat(routing): Routed hdmi signal traces and component placement.
    [LattePandaMu-Carrier.kicad_pcb]
2026-09-22 feat(routing): Routed usb 3 components.
    [LattePandaMu-Carrier.kicad_pcb]
2026-09-22 feat(routing): Optimized track routing.
    [LattePandaMu-Carrier.kicad_pcb]
2026-09-23 feat(routing): Routed ethernet connections; still need to perform length tuning on differential pairs or rerouting.
    [LattePandaMu-Carrier.kicad_pcb, ethernet.kicad_sch]
2026-09-25 feat: Moved ethernet connector and rerouted components to allow for usb 2 routing.
    [LattePandaMu-Carrier.kicad_pcb]
2026-09-25 feat(routing): Routed remaining m.2 interfaces.
    [LattePandaMu-Carrier.kicad_pcb]
2026-09-25 feat: Routed remaining m.2 passives and power.
    - Fixed capacitor values.
    [LattePandaMu-Carrier.kicad_pcb, m2_em_key.kicad_sch]
2026-09-26 feat(routing): GPIO routing
    [LattePandaMu-Carrier.kicad_pcb, gpio.kicad_sch]
2026-09-26 feat(gnd): L2 and L3 GND copper fills and gnd connections.
    [LattePandaMu-Carrier.kicad_pcb]
2026-09-26 refactor: Reworked some gnd connections to copper fills.
    [LattePandaMu-Carrier.kicad_pcb]
2026-09-27 feat(routing): Wired cpu fan connectors and components.
    [LattePandaMu-Carrier.kicad_pcb]
2026-09-27 feat(routing): Connected USB-C PD connector.
    [LattePandaMu-Carrier.kicad_pcb]
2026-09-27 feat(routing): Routed 5V U15.
    - Left Vpullup and BIOS_SEL routing for after U16 is routed with the jumper.
    [LattePandaMu-Carrier.kicad_pcb]
2026-09-27 feat(routing): Routed 3.3V U16.
    [LattePandaMu-Carrier.kicad_pcb]
2026-09-27 feat(routing): Routed pushbutton switches.
    [LattePandaMu-Carrier.kicad_pcb]
2026-09-27 feat(routing): Routed power distribution.
    [LattePandaMu-Carrier.kicad_pcb]
2026-09-27 feat(routing): Connected Vdc power distribution.
    [LattePandaMu-Carrier.kicad_pcb]
2026-09-28 feat(drc): Completed DRC check and repair for signal connections.
    [LattePandaMu-Carrier.kicad_pcb]
2026-09-28 feat(drc): fixed silkscreen issues.
    [LattePandaMu-Carrier.kicad_pcb]
2026-09-28 feat: Added front and back copper layer gnd pour.
    [LattePandaMu-Carrier.kicad_pcb]
